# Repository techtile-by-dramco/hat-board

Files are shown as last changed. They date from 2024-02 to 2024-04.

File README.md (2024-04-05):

# HAT board ✅

This PCB was developed by Guus Leenders from KU Leuven DRAMCO and should be connected to the RPI 4 on all 140 tiles.
The board is utilized in a distributed antenna or **Radioweave** infrastructure and his main function is controlling the PLL board and OLED screen. 
This HAT board has a flat cable connector to control the PLL board (see [pll-oled-hat](https://github.com/techtile-by-dramco/pll-oled-hat))

All HAT board functions listed:
* 1x Flat cable connector (PLL board connection)
* 5x Addressable RGB LEDs
* 2x User buttons
* 1x HAT output connector
* 1x OLED screen
* 1x Proximity sensor

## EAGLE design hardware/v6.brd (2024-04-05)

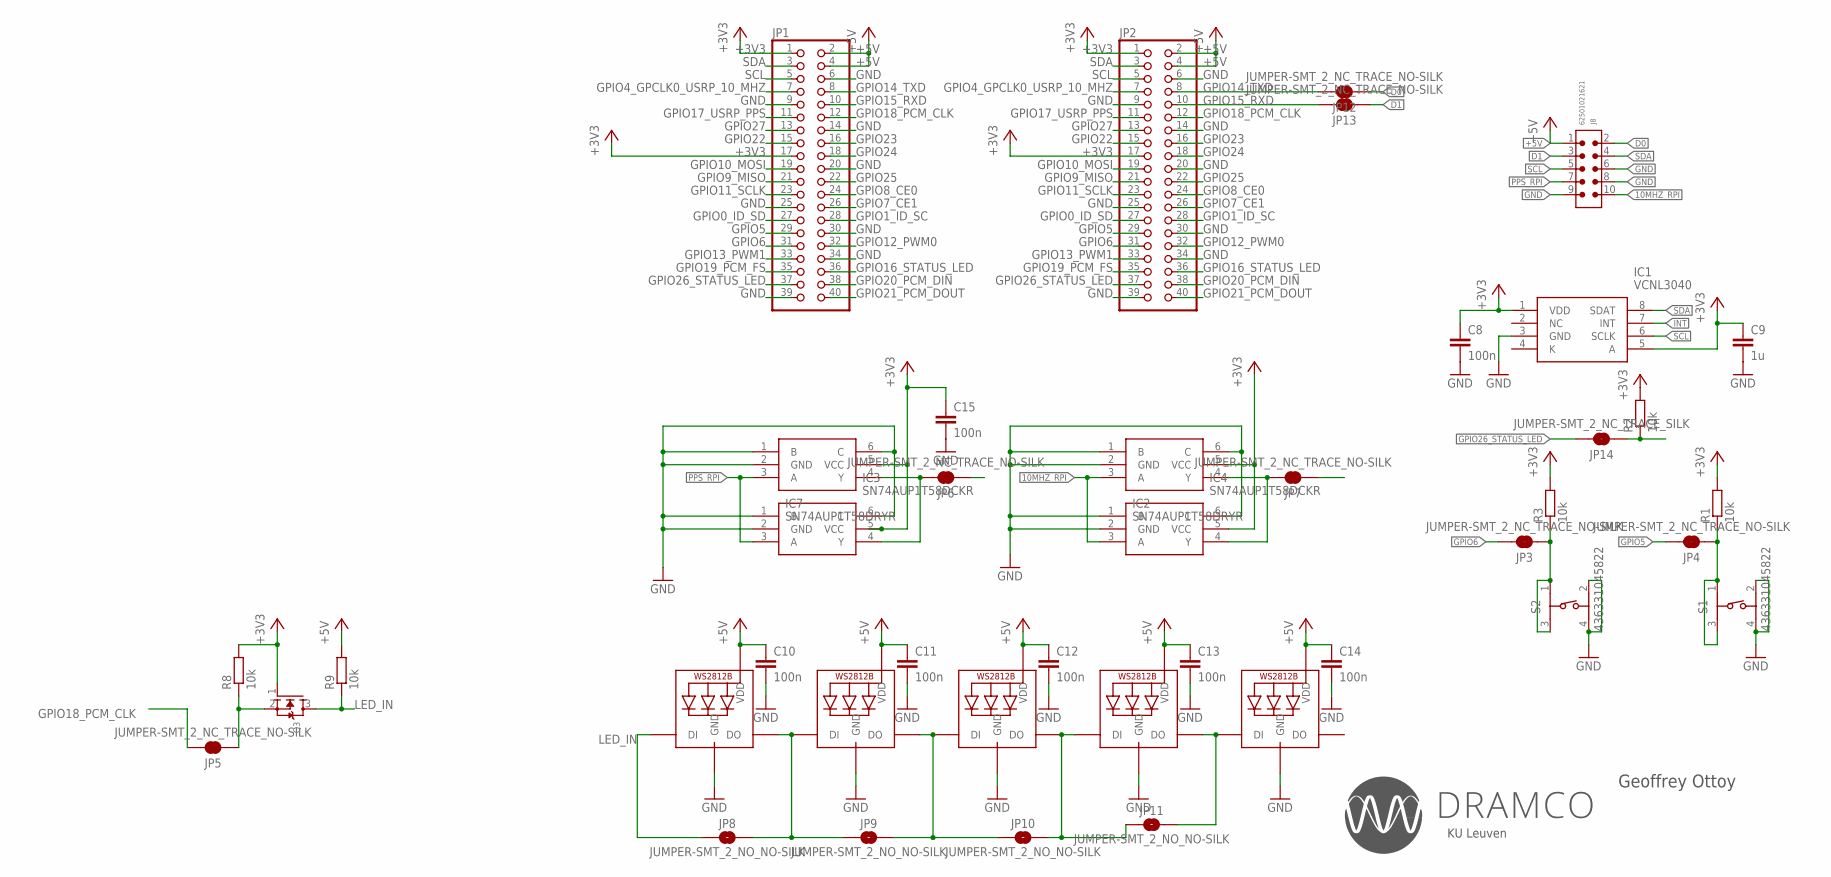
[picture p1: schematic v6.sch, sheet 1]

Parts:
C8, C10, C11, C12, C13, C14, C15: 100n; C0603
C9: 1u; C0603
IC1: VCNL3040; SON108P200X400X115-8N
IC2, IC7: SN74AUP1T58DRYR; SON50P100X145X60-6N
IC3, IC4: SN74AUP1T58DCKR; SOT65P210X110-6N
J8: 62501021621
JP1: PINHD-2X20; 2X20
JP2: PINHD-2X20/90; 2X20/90
JP3, JP4, JP5, JP6, JP7, JP12, JP13: JUMPER-SMT_2_NC_TRACE_NO-SILK; SMT-JUMPER_2_NC_TRACE_NO-SILK
JP8, JP9, JP10, JP11: JUMPER-SMT_2_NO_NO-SILK; SMT-JUMPER_2_NO_NO-SILK
JP14: JUMPER-SMT_2_NC_TRACE_SILK; SMT-JUMPER_2_NC_TRACE_SILK
LED1, LED2, LED3, LED4, LED5: WS2812B5050; WS2812B
Q3: MOSFET-NREFLOW; SOT23
R1, R2, R3, R8, R9: 10k; R0603
S1, S2: 436331045822; 4363X10458XX

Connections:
10MHZ_RPI: IC2.3 (A), IC4.3 (A), J8.10
+3V3: C8.1, C9.1, C15.1, IC1.1 (VDD), IC1.5 (A), IC2.5 (VCC), IC3.5 (VCC), IC4.5 (VCC), IC7.5 (VCC), JP1.1, JP1.17, JP2.1, JP2.17, Q3.1 (G), R1.2, R2.2, R3.2, R8.2; also elsewhere on the board
+5V: C10.1, C11.1, C12.1, C13.1, C14.1, J8.1, JP1.2, JP1.4, JP2.2, JP2.4, LED1.1-VDD (VDD), LED2.1-VDD (VDD), LED3.1-VDD (VDD), LED4.1-VDD (VDD), LED5.1-VDD (VDD), R9.2
D0: J8.2, JP12.1
D1: J8.3, JP13.1
GND: C8.2, C9.2, C10.2, C11.2, C12.2, C13.2, C14.2, C15.2, IC1.3 (GND), IC2.1 (B), IC2.2 (GND), IC2.6 (C), IC3.1 (B), IC3.2 (GND), IC3.6 (C), IC4.1 (B), IC4.2 (GND), IC4.6 (C), IC7.1 (B), IC7.2 (GND), IC7.6 (C), J8.6, J8.8, J8.9, JP1.6, JP1.9, JP1.14, JP1.20, JP1.25, JP1.30, JP1.34, JP1.39, JP2.6, JP2.9, JP2.14, JP2.20, JP2.25, JP2.30, JP2.34, JP2.39, LED1.3-GND (GND), LED2.3-GND (GND), LED3.3-GND (GND), LED4.3-GND (GND), LED5.3-GND (GND), S1.2 (4), S1.4 (2), S2.2 (4), S2.4 (2); also elsewhere on the board
GPIO0_ID_SD: JP1.27, JP2.27
GPIO1_ID_SC: JP1.28, JP2.28
GPIO4_GPCLK0_USRP_10_MHZ: JP1.7, JP2.7, JP7.1
GPIO5: JP1.29, JP2.29, JP4.2
GPIO6: JP1.31, JP2.31, JP3.2
GPIO7_CE1: JP1.26, JP2.26
GPIO8_CE0: JP1.24, JP2.24
GPIO9_MISO: JP1.21, JP2.21
GPIO10_MOSI: JP1.19, JP2.19
GPIO11_SCLK: JP1.23, JP2.23
GPIO12_PWM0: JP1.32, JP2.32
GPIO13_PWM1: JP1.33, JP2.33
GPIO14_TXD: JP1.8, JP2.8, JP12.2
GPIO15_RXD: JP1.10, JP2.10, JP13.2
GPIO16_STATUS_LED: JP1.36, JP2.36
GPIO17_USRP_PPS: JP1.11, JP2.11, JP6.1
GPIO18_PCM_CLK: JP1.12, JP2.12, JP5.2
GPIO19_PCM_FS: JP1.35, JP2.35
GPIO20_PCM_DIN: JP1.38, JP2.38
GPIO21_PCM_DOUT: JP1.40, JP2.40
GPIO22: JP1.15, JP2.15
GPIO23: JP1.16, JP2.16
GPIO24: JP1.18, JP2.18
GPIO25: JP1.22, JP2.22
GPIO26_STATUS_LED: JP1.37, JP2.37, JP14.2
GPIO27: JP1.13, JP2.13
INT: IC1.7 (INT), JP14.1, R2.1
LED_IN: JP8.1, LED1.4-DIN (DI), Q3.3 (D), R9.1
unnamed: IC3.4 (Y), IC7.4 (Y), JP6.2
unnamed: JP5.1, Q3.2 (S), R8.1
unnamed: IC2.4 (Y), IC4.4 (Y), JP7.2
unnamed: JP3.1, R3.1, S2.1 (3), S2.3 (1)
unnamed: JP8.2, JP9.1, LED1.2-DOUT (DO), LED2.4-DIN (DI)
unnamed: JP9.2, JP10.1, LED2.2-DOUT (DO), LED3.4-DIN (DI)
unnamed: JP10.2, JP11.1, LED3.2-DOUT (DO), LED4.4-DIN (DI)
unnamed: JP11.2, LED4.2-DOUT (DO), LED5.4-DIN (DI)
unnamed: JP4.1, R1.1, S1.1 (3), S1.3 (1)
PPS_RPI: IC3.3 (A), IC7.3 (A), J8.7
SCL: IC1.6 (SCLK), J8.5, JP1.5, JP2.5; also elsewhere on the board
SDA: IC1.8 (SDAT), J8.4, JP1.3, JP2.3; also elsewhere on the board

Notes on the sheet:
Geoffrey Ottoy
KU Leuven

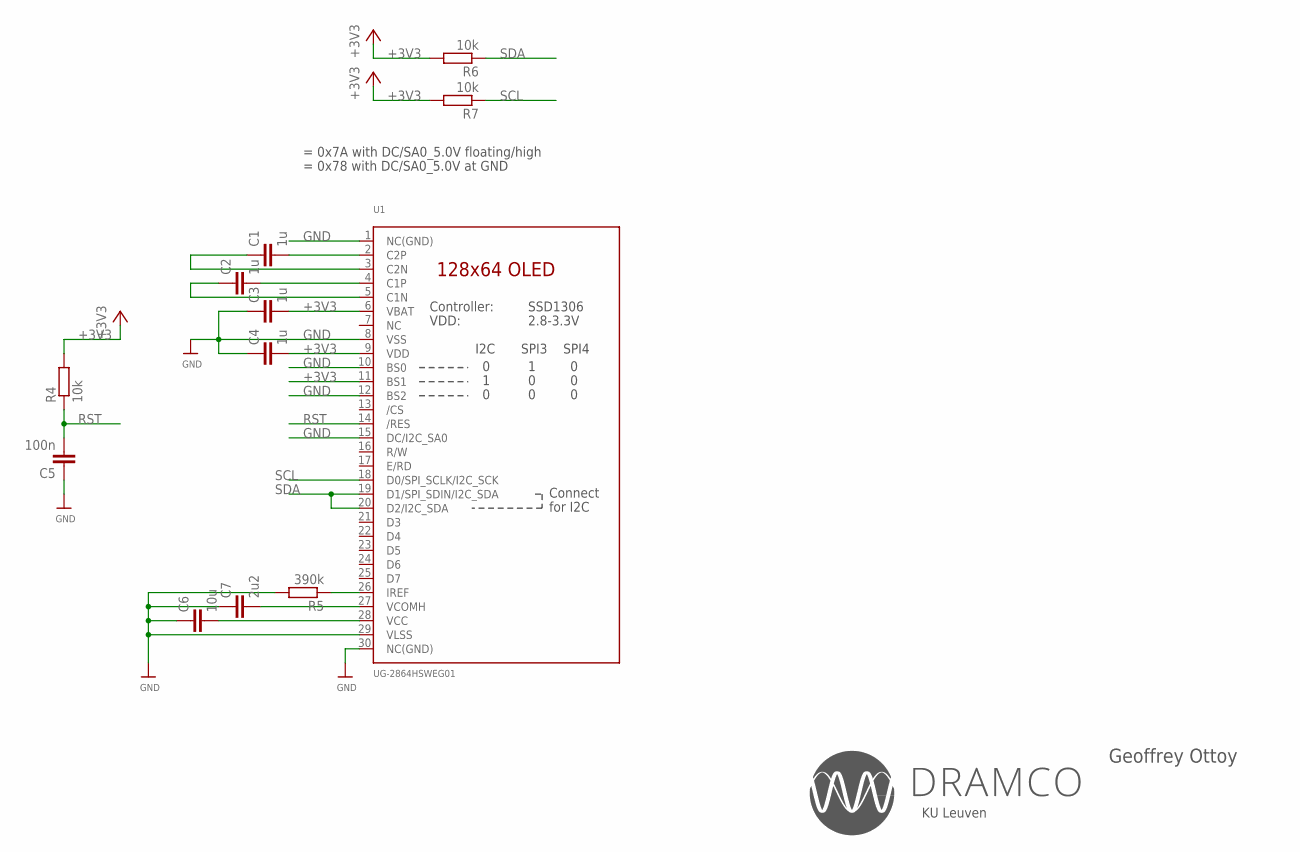
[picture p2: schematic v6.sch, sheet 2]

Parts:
C1, C2, C3, C4: 1u; C0603
C5: 100n; C0603
C6: 10u; C0603
C7: 2u2; C0603
R4, R6, R7: 10k; R0603
R5: 390k; R0603
U1: UG-2864HSWEG01; UG-2864HSWEG01_0.96IN_WRAPAROUND

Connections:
+3V3: C3.2, C4.2, R4.2, R6.2, R7.2, U1.6 (VBAT), U1.9 (VDD), U1.11 (BS1); also elsewhere on the board
GND: C3.1, C4.1, C5.1, C6.1, C7.1, R5.2, U1.1 (NC(GND)), U1.8 (VSS), U1.10 (BS0), U1.12 (BS2), U1.15 (DC/I2C_SA0), U1.29 (VLSS), U1.30 (NC(GND)); also elsewhere on the board
unnamed: C1.2, U1.2 (C2P)
unnamed: C6.2, U1.28 (VCC)
unnamed: C7.2, U1.27 (VCOMH)
unnamed: R5.1, U1.26 (IREF)
unnamed: C1.1, U1.3 (C2N)
unnamed: C2.2, U1.4 (C1P)
unnamed: C2.1, U1.5 (C1N)
RST: C5.2, R4.1, U1.14 (/RES)
SCL: R7.1, U1.18 (D0/SPI_SCLK/I2C_SCK); also elsewhere on the board
SDA: R6.1, U1.19 (D1/SPI_SDIN/I2C_SDA), U1.20 (D2/I2C_SDA); also elsewhere on the board

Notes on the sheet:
= 0x7A with DC/SA0_5.0V floating/high
= 0x78 with DC/SA0_5.0V at GND
Geoffrey Ottoy
KU Leuven

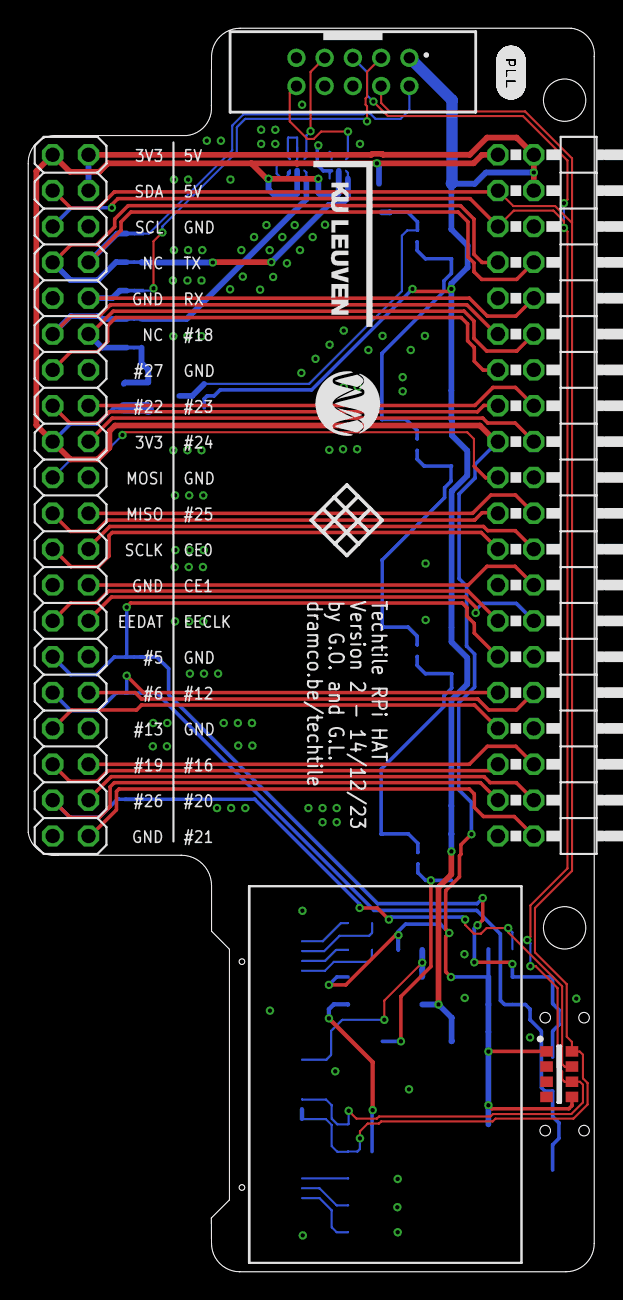
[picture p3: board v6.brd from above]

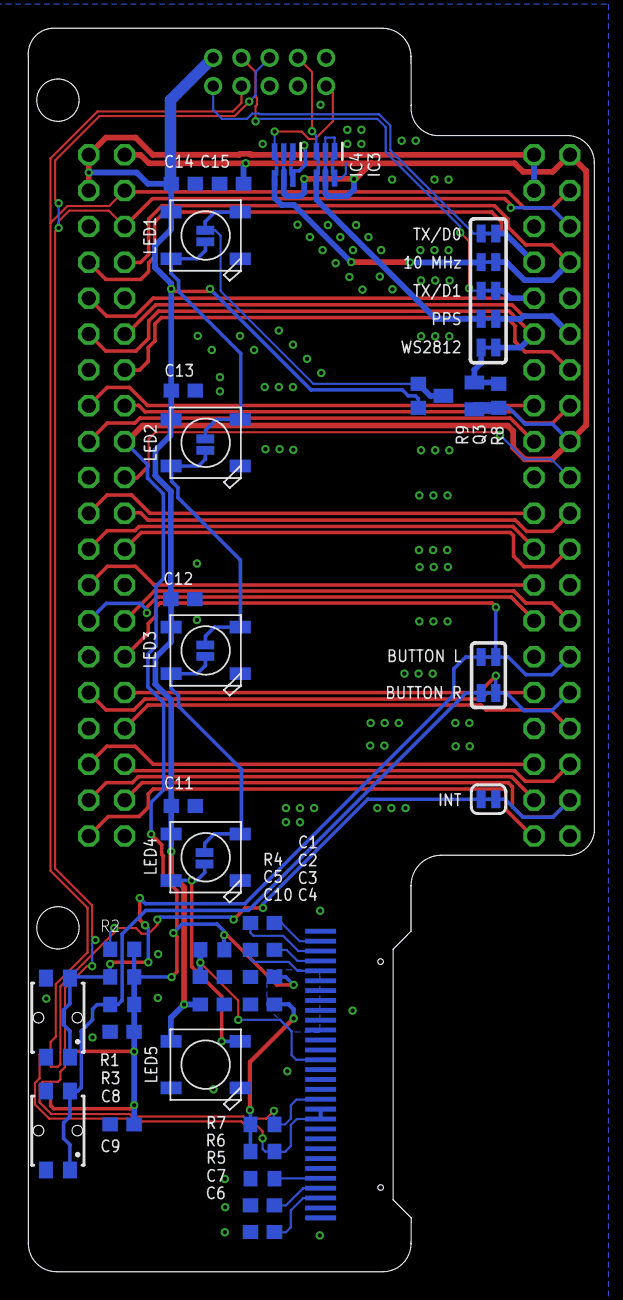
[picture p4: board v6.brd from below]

Board: 2 copper layers, 40.1 x 88.1 mm, 53 parts (48 on the bottom side), 54 nets.

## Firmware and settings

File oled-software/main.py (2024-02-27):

# Program to control the leds and LCD of the techtile rpi
# To be run as a service

import time
import os
import sys
import subprocess
import threading
from multiprocessing import Queue
import RPi.GPIO as GPIO
from threading import Timer, Thread
import atexit

from board import SCL, SDA
import busio
#from PIL import Image, ImageDraw, ImageFont
#import adafruit_ssd1306

from buttons import Buttons
from proximity_sensor import ProximitySensor
from leds import LEDs
from screen import Screen
from statistics import Statistics

BUTTON_LEFT_GPIO = 5
BUTTON_RIGHT_GPIO = 6
PROXIMITY_INT_GPIO = 26
LEDS_GPIO = 18
NUMBER_OF_LEDS = 5

buttons = Buttons({"left": BUTTON_LEFT_GPIO, "right": BUTTON_RIGHT_GPIO})
proximity_sensor = ProximitySensor(PROXIMITY_INT_GPIO)
leds = LEDs(LEDS_GPIO, 5)
screen = Screen()
statistics = Statistics()

def scroll_left():
    screen.button_scroll_page(-1, 60)
    screen.sleep(55)
    leds.backlight()
    leds.resume(55)

def scroll_right():
    screen.button_scroll_page(1, 60)
    screen.sleep(55)
    leds.backlight()
    leds.resume(55)

def turn_on():
    screen.wake()
    leds.backlight()

def turn_off():
    screen.sleep(20)
    leds.resume(20)

def exit_handler():
    screen.sleep(0)
    leds.resume(0)

def shutdown():
    screen.sleep(0)
    leds.resume(0)
    subprocess.call(['shutdown', '-h', 'now'], shell=False)

if __name__ == '__main__':
    GPIO.setmode(GPIO.BCM)
    buttons.register_callback("left", "short", scroll_left)
    buttons.register_callback("right", "short", scroll_right)
    buttons.register_callback("left", "medium", scroll_left)
    buttons.register_callback("right", "medium", scroll_right)

    buttons.register_callback("right", "multiple_long", shutdown)
    buttons.register_callback("right", "multiple_extra_long", shutdown)

    proximity_sensor.register_callback("closing", turn_on)
    proximity_sensor.register_callback("away", turn_off)
    
    leds.sync_effect_on("time", 60)
    leds.start_heartbeat()

    screen.register_statistics(statistics)

    atexit.register(exit_handler)

    while True:
        time.sleep(1)
        # Almost everything happens in callbacks, we just need to check the cpu for the high cpu led effect
        if not leds.backlight_on and not screen.awake:
            if statistics.get("cpu") > 50:
                leds.start_bounce()
            elif statistics.get("cpu") < 40:
                leds.start_heartbeat()

    

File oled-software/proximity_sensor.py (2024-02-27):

import RPi.GPIO as GPIO
from vcnl3040 import VCNL3040

def proximity_callback(gpio):
    proximity_sensor.callback()

proximity_sensor = None

class ProximitySensor:
    def __init__(self, gpio):
        global proximity_sensor
        proximity_sensor = self

        self.vcnl = VCNL3040()

        GPIO.setup(gpio, GPIO.IN)
        GPIO.add_event_detect(gpio, GPIO.BOTH, callback=proximity_callback, bouncetime=10)

        self.vcnl.set_LED_current(180)
        self.vcnl.set_duty_cycle(80)
        self.vcnl.set_integration_time(8)
        self.vcnl.set_resolution(16)
        self.vcnl.set_forced_mode(False)
        
        self.vcnl.enable_interrupt_proximity_mode()
        self.vcnl.set_interrupt_mode("closing_and_away")
        
        self.vcnl.set_persistence(4)
        self.vcnl.start()

        self.calibrate()
        self.proximity = False

    def calibrate(self, low_threshold=None, delta=4):
        if low_threshold is None:
            reading = self.vcnl.get_data()
            self.vcnl.set_low_threshold(reading)
            self.vcnl.set_high_threshold(reading + delta)
        else:
            self.vcnl.set_low_threshold(low_threshold)
            self.vcnl.set_high_threshold(low_threshold + delta)


    def register_callback(self, action, function, *args, **kwargs):
        setattr(self, action + "_callback", function)
        setattr(self, action + "_args", args)
        setattr(self, action + "_kwargs", kwargs)

    def callback(self):
        if self.vcnl.get_data() < 3:
            self.proximity = False
        else:
            self.proximity = True

        self.evaluate_callback()

    def evaluate_callback(self):
        if self.proximity == True:
            self.execute_callback("closing")
        else:
            self.execute_callback("away")

    def execute_callback(self, action):
        if hasattr(self, action+"_callback"):
            f = getattr(self, action + "_callback")
            if getattr(self, action + "_args") is not None and getattr(self, action + "_kwargs") is not None: 
                f(*getattr(self, action + "_args"), **getattr(self, action + "_kwargs"))
            elif getattr(self, action + "_args") is not None: 
                f(*getattr(self, action + "_args"))
            elif getattr(self, action + "_kwargs") is not None: 
                f(**getattr(self, action + "_kwargs"))
            else:
                f()

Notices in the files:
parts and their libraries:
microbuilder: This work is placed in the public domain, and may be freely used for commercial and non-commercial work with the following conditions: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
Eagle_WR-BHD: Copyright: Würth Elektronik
